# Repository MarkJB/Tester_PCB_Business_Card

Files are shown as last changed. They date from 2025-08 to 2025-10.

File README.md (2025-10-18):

# Tester PCB Business Card

A PCB Business Card designed by a tester, for testers (QA Engineers)

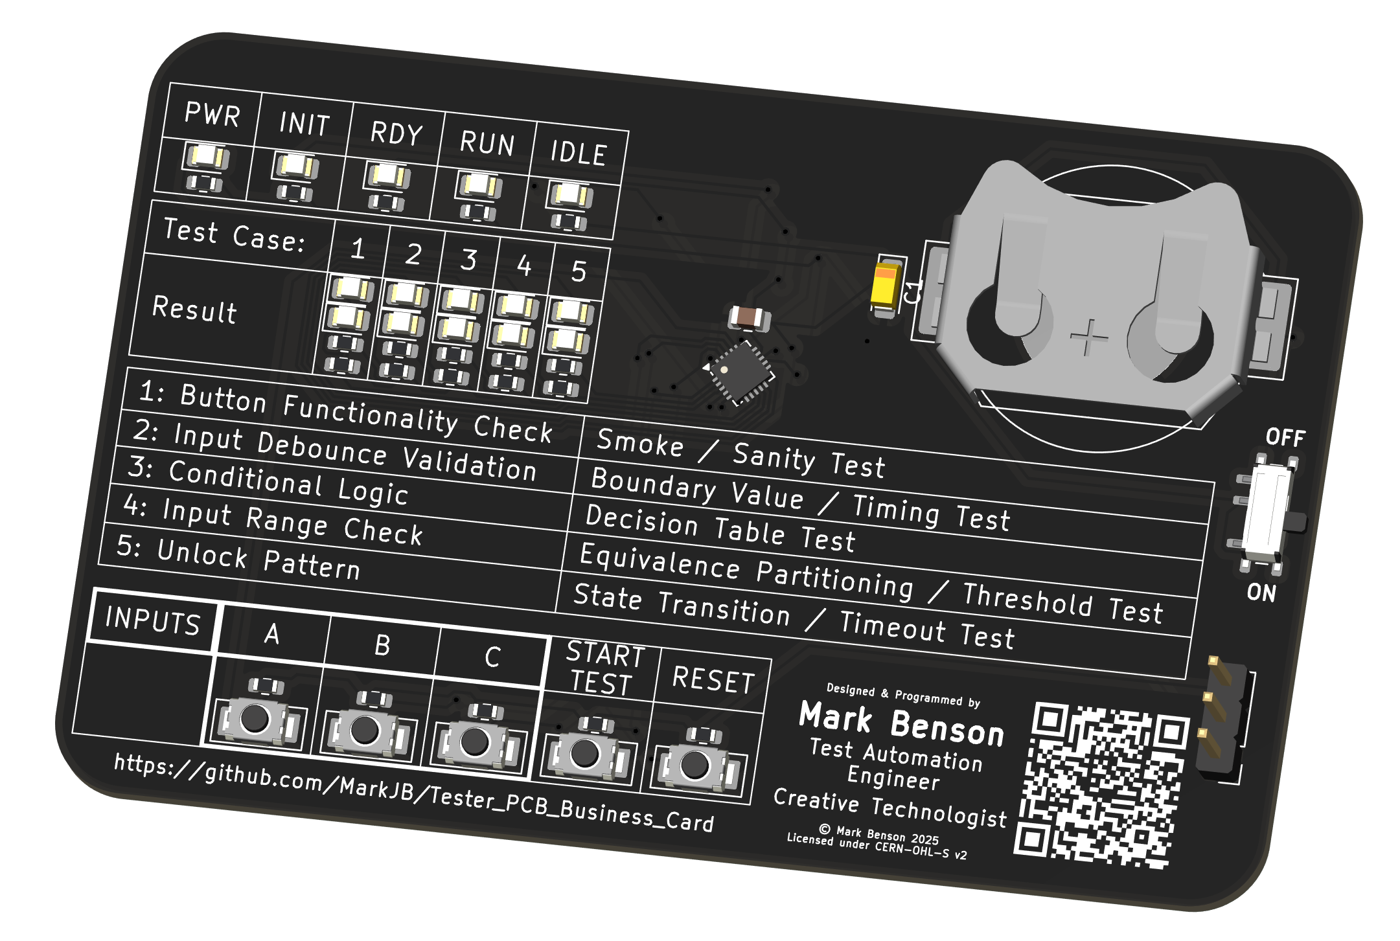
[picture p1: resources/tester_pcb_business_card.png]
Kicad 9 PCB Render


I've always liked the PCB business cards I've seen people design. They often have an interesting story about the why and the how, and sometimes even lead to a job offer as a result!

> Note: For any recruiters or prospective employers who end up here, I'm a software tester specializing in WebUI test automation. Electronics and hardware is a hobby (and occasionally a freelance gig in the Creative Technologist/Arts and Technology space)

I wanted to give it a go but couldn't think of anything compelling that was related to my primary industry (QA, Software Testing & Test Automation). Then I saw a recent [pong example on Hackaday](https://hackaday.com/2025/08/13/pcb-business-card-plays-pong-attracts-employer/) which made me wonder whether the author had done much testing, and that sparked the idea of creating a PCB business card all about testing.

There are 5 'test cases'\*, each one designed to be a little bit harder than the previous one and to focus on a different class of test. The hardware is somewhat limited, so how well each of the tests achieves its intended goal or how true it is to its test type is open for debate and I welcome feedback from actual testers!

The idea is that a tester should be able to look at the test case description, its test type and, given the available inputs and output, figure out how to get the tests to pass, treating it as a sort of black-box exploratory test session. Think of it as a fidget toy for tester.

That all said, I've not yet had any feedback from any testers so I don't know if its too easy or too hard. If you want to cheat, dig into this repo and you'll find the test case BDD scenarios and solutions (which I have deliberately not linked from any of the main READMEs), or as an alternative you can read the code (either the main firmware or the simulator should provide a white-box experience).

\* I use the term "test cases" to refer to the tests that the hardware is presenting to the end user to 'execute', but in some places I have also created actual tests for the code as well (like the Playwright tests for the simulator).

> Note: There may be minor differences between the simulator and the actual hardware due to implementation details or I changed direction while working on the firmware and haven't gotten round to updating the simulator.

So here is Rev A:

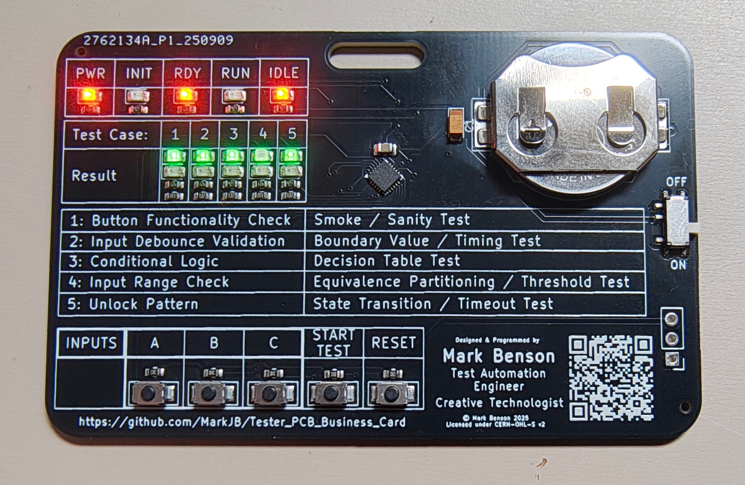
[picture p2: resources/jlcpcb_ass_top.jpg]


This is based on the CH32V003F4U6. A 27¢ micro controller with a one-wire programmer that costs less than $8. I had no experience with this when I started this project, but cost was a big factor with the card. I'm aiming for sub $2 per unit so I can a) afford to get a handful made and b) give them away at conferences and networking events.

> Note: I added a slot for attaching to a lanyard as I intend to give these out at networking and conference events.

This repo includes:

# Hardware

The [schematic](./resources/schematic.pdf), PCB design, BoM and JLCPCB ready production files [Kicad 9 files here](./hardware/)

# Software

## Simulator

Simulator [README](./software/simulator)

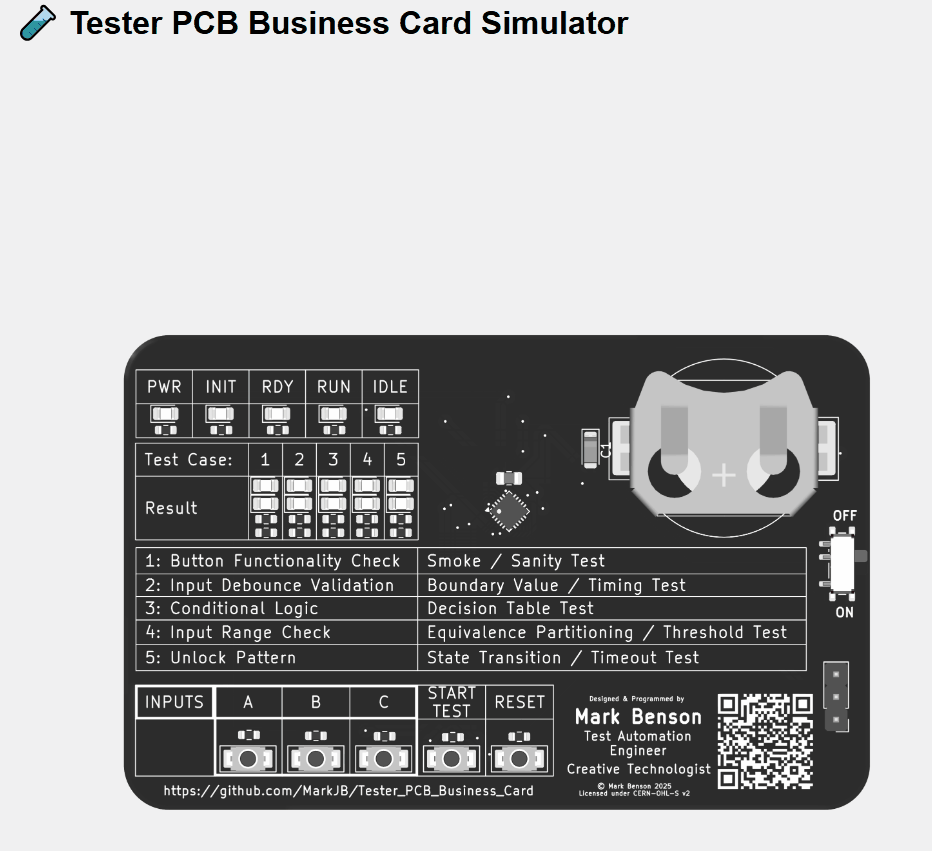
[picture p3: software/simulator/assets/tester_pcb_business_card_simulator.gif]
Tester PCB Preview


The simulator is built, tested and (if successful) deployed to GitHub pages by a [GitHub Actions pipeline](https://github.com/MarkJB/Tester_PCB_Business_Card/actions)

You can play with the deployed simulator here: [Simulator Demo](https://markjb.github.io/Tester_PCB_Business_Card/)

## Firmware

Uses platformio and the ch32fun framework.

[Main firmware](./software/firmware/tester_runtime/): The main firmware containing tests, test case runner, LED control, button functions etc.

[Board check](./software/firmware/board_check/): Simple test firmware to confirm LEDs and buttons are connected and working. Mainly used for testing hand assembled prototype boards.

[LED Tune](./software/firmware/led_tune/): Simple firmware to allow manual tuning of resistor values. shouldn't need this again unless the LEDs are changed for ones that are significantly different.

# Licenses

Copyright Mark Benson 2025

The hardware is licensed under the CERN-OHL-S v2 license.
The software is licensed under the MIT license.

Usual disclaimer - No warranty implied or given for any use or outcome of any of the available materials, etc. 

This isn't a toy, it's not suitable for children. As it's not in a case, there is a risk of short circuiting the components and battery, resulting in damage or overheating, so do not put it in your pocket or bag or anywhere where metal objects could cause short circuit. Note: Battery should be inserted + side up. Incorrectly inserted battery will short out resulting in damage or overheating. Use at your own risk.

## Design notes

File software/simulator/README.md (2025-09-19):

# 🧪 Tester PCB Business Card Simulator

An interactive browser based simulator for the Tester PCB Business Card — designed to evaluate the user experience before the hardware was available. Also to check if the test cases were interesting and engaging and not too obscure for the end user/tester.

Designed in collaboration with Co-pilot - I don't think I'd have been able to spin this up as quickly or get as far as I have in a short space of time without it.

The code went through a number of iterations and ended up informing a lot of decisions that carried over to the real firmware. For instance, I ended up creating a simple test runner with setup and teardown as well as abstracting the hardware. I ended up feeding the test cases along with the BDD scenarios into CoPilot to help generate the test cases for the firmware.

I've also spent some time creating Playwright tests and adding a workflow to build, test and deploy the simulator to github pages. You can test out [the simulator here](https://markjb.github.io/Tester_PCB_Business_Card/)

Simulator Demo  
_Animated preview of the simulator in action - Power on/off, system init, reset, start test, restart test_

---

## 🚀 Getting Started

This simulator runs in the browser using JavaScript and SVG overlays.

### 📦 Prerequisites

- Node

### 🛠 Setup Instructions

1. **Checkout the repo**
   ```bash
   git clone https://github.com/MarkJB/Tester_PCB_Business_Card.git
   ```
2. **Navigate to the simulator folder**
   ```
   cd Tester_PCB_Business_Card/software/simulator
   ```
   3. **Install dependencies**
   ```
   npm ci
   ```
   4. **Start the simulator**
   ```
   npm run dev
   ```
   5. **Open simulator in browser**
   ```
   Go to http://localhost:5173
   ```
   (or whatever port it opens on for you)

### 🛠 Usage Instructions

The power switch toggles the power on/off
The input buttons A, B & C are used in the tests. Pressing one of these will briefly light up the INIT status LED.
The "START TEST" button will start a test run of all tests. Each test runs for 5 seconds. The result will be shown at the end of the test (Green for pass, red for fail, TBD flashing green for warning). Press "START TEST" to advance to the next test or restart the test run when it is finished.
Pressing "RESET" will reset the simulator and test progress.

Its up to you to figure out how to pass all the tests.

Note: There are spoilers/solutions in the repo.

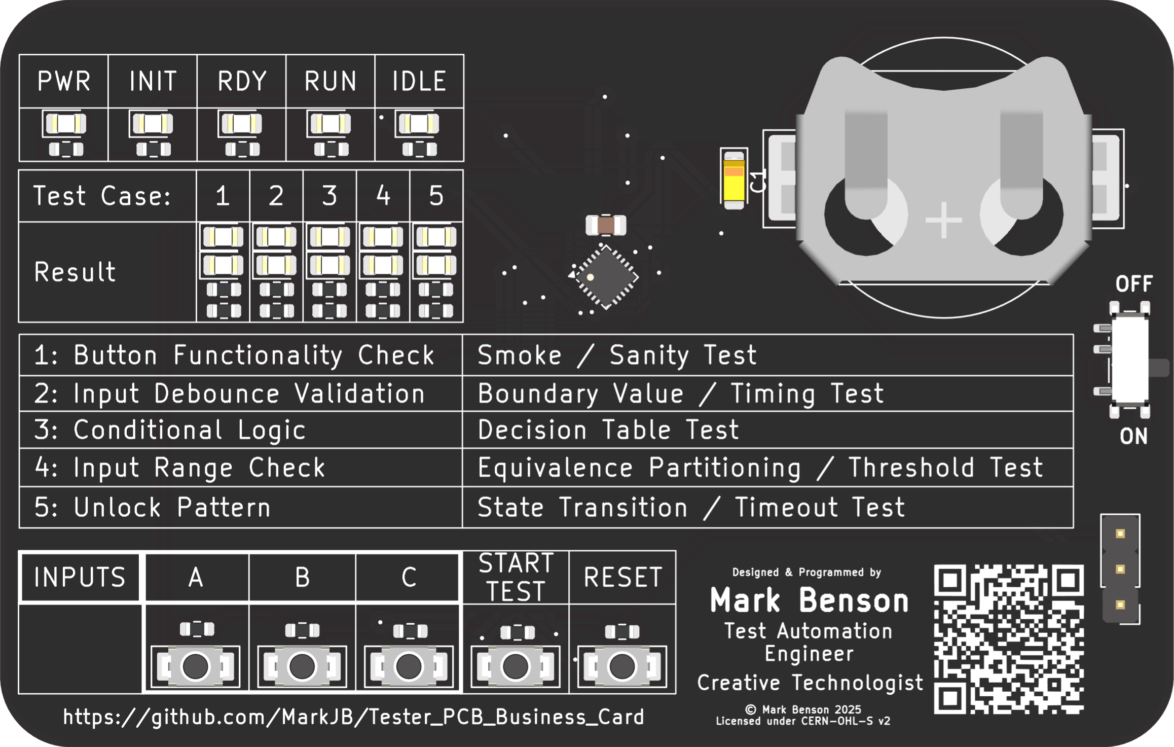
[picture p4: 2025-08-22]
software/simulator/assets/background.png

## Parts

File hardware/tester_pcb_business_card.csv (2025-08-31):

Value | Reference | Footprint | LCSC
CR2032 | BT1 | custom:MY-2032-12 | C964833
10u | C1 | Capacitor_Tantalum_SMD:CP_EIA-3216-18_Kemet-A | C7171
0.1u | C2 | Capacitor_SMD:C_0805_2012Metric | C49678
PWR | D1 | LED_SMD:LED_0805_2012Metric | C84256
INIT | D2 | LED_SMD:LED_0805_2012Metric | C84256
RDY | D3 | LED_SMD:LED_0805_2012Metric | C84256
RUN | D4 | LED_SMD:LED_0805_2012Metric | C84256
RA_R | D6 | LED_SMD:LED_0805_2012Metric | C84256
RB_R | D7 | LED_SMD:LED_0805_2012Metric | C84256
RC_R | D8 | LED_SMD:LED_0805_2012Metric | C84256
RD_R | D9 | LED_SMD:LED_0805_2012Metric | C84256
RE_R | D10 | LED_SMD:LED_0805_2012Metric | C84256
RA_G | D11 | LED_SMD:LED_0805_2012Metric | C2297
RB_G | D12 | LED_SMD:LED_0805_2012Metric | C2297
RD_G | D14 | LED_SMD:LED_0805_2012Metric | C2297
RE_G | D15 | LED_SMD:LED_0805_2012Metric | C2297
IDLE | D5,D13 | LED_SMD:LED_0805_2012Metric | C2297,C84256
SWIO | J1 | Connector_PinHeader_2.54mm:PinHeader_1x03_P2.54mm_Vertical
470 | R1,R2,R3,R4,R5,R11,R13,R15,R17,R19 | Resistor_SMD:R_0603_1608Metric | C23179
3.3k | R12,R14,R16,R18,R20 | Resistor_SMD:R_0603_1608Metric | C22978
10k | R6,R7,R8,R9,R10 | Resistor_SMD:R_0603_1608Metric | C25804
PWR | SW1 | custom:SW_SPDT_Shouhan_MSK12C02 | C431540
A | SW2 | custom:BTN_XUNPU_TS_1088-AR02016 | C720477
B | SW3 | custom:BTN_XUNPU_TS_1088-AR02016 | C720477
C | SW4 | custom:BTN_XUNPU_TS_1088-AR02016 | C720477
D | SW5 | custom:BTN_XUNPU_TS_1088-AR02016 | C720477
RST | SW6 | custom:BTN_XUNPU_TS_1088-AR02016 | C720477
CH32V003FxUx | U1 | Package_DFN_QFN:QFN-20-1EP_3x3mm_P0.4mm_EP1.65x1.65mm | C5299908

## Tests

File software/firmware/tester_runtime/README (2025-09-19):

Compile and upload with PlatformIO (this should automatically fetch the ch32fun framework) using a WCH-LinkE programmer.

Firmware based on design spec, BDD scenarios and simulator (test case) code.

If you have problems uploading via VSCode, try downloading the (openwch/openocd_wch repo)[https://github.com/openwch/openocd_wch]. This repo provides a customized version of the openocd.exe util that works with the WHC-Link-E programmer and running the following command:

openocd_wch\bin\openocd.exe -f openocd_wch\bin\wch-riscv.cfg -c "program path\to\firmware.elf verify reset exit"

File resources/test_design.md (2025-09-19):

# 🧪 Test Suite Overview

| Test Case # | Name | Type |
| --- | --- | --- |
| 1 | Button Functionality Check | Smoke / Sanity Test |
| 2 | Input Debounce Validation  | Boundary Value / Timing Test |
| 3 | Conditional Logic | Decision Table / Branch Test |
| 4 | Input Range Check | Equivalence Partitioning / Threshold Test |
| 5 | Unlock Pattern | State Transition / Timeout Test |

### 💡 Test Result Feedback

| Outcome | LED Behavior |
| --- | --- |
| ✅Pass | 🟢⚫ |
| ⚠️Warning | (🟢/⚫)⚫ (Blinking Green) |
| ❌Fail | ⚫🔴 |

## 🚨⚠️ Warning! Spoilers Ahead!! ⚠️🚨

We should split the test description and the steps/solutions into separate files so this can serve as a test guide without giving away the solution

## 🧪 Test Case 1: Button Functionality Check

**Instruction**: Press each button in turn.  
**Type**: Smoke / Sanity Test

#### Scenario: Validate input button functionality

```gherkin
Given the system state is powered on and in an idle state
When I press each input button in sequence
Then each button press is registered by the system
And the system is ready for further testing
```

---

## 🧪 Test Case 2: Input Debounce Validation – Boundary Value / Timing Test

> ### Note: This needs some clarification of what we are trying to achieve - what are we testing - that it works or rejects?

**Instruction**: Press button B twice with a specific delay between presses.
**Type**: Boundary Value / Timing Test

### Scenario: Validate system debounce threshold using timed input

```gherkin
Given the system is idle and ready to receive input
When I press button B twice with a delay greater than 30ms and less than 200ms
Then the system registers both presses as valid input

Given the system is idle and ready to receive input
When I press button B twice with a delay less than 30ms
Then the system ignores the second press as invalid input (debounce)
```

### 🧠 What’s Being Tested

> “This test models a system that filters out rapid, repeated signals. The tester must press B twice with a precise delay to determine the system’s debounce threshold.”

- **Boundary**: 100ms (tbd)
- **Pass**: Two presses >30ms apart + <200ms apart → both counted
- **Fail**: Two presses <30ms apart → second ignored

### 🔧 Test Logic

| Timing Between Presses | Interpretation | Test Outcome |
| --- | --- | --- |
| >100ms | Treated as valid input | ✅ Pass |
| <100ms | Treated as bounce → ignored | ❌ Fail |

---

## 🧪 Test Case 3: Conditional Logic – Decision Table Test

**Instruction**: Press any combination of A, B, and C within 5 seconds.
**Type**: Decision Table / Branch Test

### Scenario: Evaluate system logic based on input combinations

```gherkin
Given the system is idle and ready to receive input
When the user presses any combination of buttons (individually or combined) A, B, and C within a 5-second window
Then the system stores the input state until the timeout expires
And the system evaluates the final input state against its decision table
```

> Note: Pressing a button will set its state and pressing it again will unset it.

### 🧠 What’s Being Tested

> “This test models decision table logic. The tester must deduce the correct input combination by observing system outcomes and reasoning through partial correctness.”

- **Inputs**: A, B, C
- **Time Limit**: 5 seconds
- **Outcome Types**:
  - ✅ **Pass** → Correct combination
  - ⚠️ **Warning** → Partial match
  - ❌ **Fail** → Incorrect or no input

### 🔧 Test Logic

| A | B | C | Outcome | Reasoning |
| --- | --- | --- | --- | --- |
| 0 | 0 | 0 | Fail | No input → no correct signal |
| 0 | 0 | 1 | Warning | C alone → partial match |
| 0 | 1 | 0 | Warning | B alone → partial match |
| 0 | 1 | 1 | Pass | ✅ B + C → correct combo |
| 1 | 0 | 0 | Fail | A alone → incorrect input |
| 1 | 0 | 1 | Warning | A + C → C is good, A is not |
| 1 | 1 | 0 | Warning | A + B → B is good, A is not |
| 1 | 1 | 1 | Warning | B + C is good, but A degrades combo |

---

## 🧪 Test Case 4: Input Range Check – Equivalence Partitioning / Threshold Test

**Instruction**: Provide values for A, B, and/or C within a 5-second window.
**Type**: Equivalence Partitioning / Threshold Test

### Scenario: System validates input ranges after timeout

```gherkin
Given the system is idle and ready to receive input
When the user provides values for inputs A, B, and/or C within a 5-second window
Then the system stores the final input state at the end of the time window
And the system evaluates each input independently against its valid range
```

### 🧠 What’s Being Tested

> “This test models per-input validation using equivalence partitioning. Each input is evaluated independently against its valid range. It teaches testers to think in terms of input classes and boundary sensitivity.”

### 📊 Example Outcomes

| A | B | C | Outcome Description |
| --- | --- | --- | --- |
| 6 | 8-11 | 3 | ✅ All valid → pass |
| 5 or 7 | 7 or 12 | 2 or 4 | ⚠️ borderline → warning (red flashing - I originally intended to use bicolour LEDs which could produce Green/Red/Orange but they were too expensive) |
| 0 | 2 | 0 | ❌ B invalid → fail |
| 0 | 0 | 0 | ❌ No input → fail |
| 7 | 0 | 0 | ✅ A valid → pass, others ignored |
| 0 | 8 | 0 | ✅ B valid → pass, others ignored |
| 0 | 0 | 3 | ✅ C valid → pass, others ignored |

---

## 🧪 Test Case 5: Unlock Pattern – State Transition / Timeout + Recovery

**Instruction**: Enter the correct unlock code within the time limit.  
**Type**: State Transition, Timeout Handling

---

### 📜 Scenario: System transitions through unlock states based on input sequence

```gherkin
Scenario: Successful unlock
  Given the unlock test is in progress
  When the user enters the sequence A → B → C → B → A
  Then the system transitions through INIT, STEP_1, STEP_2, STEP_3, and STEP_4
  And the system enters the PASS state
  And the system is unlocked

Scenario: Incorrect unlock sequence
  Given the unlock test is in progress
  When the user enters any 5-button sequence that does not match A → B → C → B → A
  Then the system enters the RECOVERY state
  And the test case LEDs stop alternating
  And the FAIL LED blinks rapidly
  And the user has 5 seconds to reset the test by pressing C → C

Scenario: Recovery success
  Given the system is in the RECOVERY state
  When the user presses C → C within 5 seconds
  Then the RECOVERY timeout is cancelled
  And the FAIL LED is cleared
  And the test case LEDs resume alternating
  And the user may retry the unlock sequence

Scenario: Recovery failure
  Given the system is in the RECOVERY state
  When the user does not press C → C within 5 seconds
  Then the system enters the FAIL state
  And the FAIL LED remains solid
```

### 🧭 Objective

Simulate a system requiring a precise unlock pattern:  
`A → B → C → B → A`

- Input must be exactly 5 button presses
- Incorrect sequence triggers recovery opportunity
- Recovery: `C → C` within 5 seconds

---

### 🛠️ Setup

- **Test Duration**: 10 seconds total from first input
- **Input Limit**: Exactly 5 button presses
- **Correct Sequence**:
  1. A → INIT
  2. B → STEP_1
  3. C → STEP_2
  4. B → STEP_3
  5. A → PASS
- **Incorrect Sequence**: Any 5-button input that does not match the above
- **Recovery Trigger**: Only after incorrect 5-button input
- **Recovery Window**: 5 seconds to enter `C → C`
- **Post-Recovery**: Test resets, user may retry

---

### 💡 LED Feedback

| State | LED Behavior |
| --- | --- |
| In Progress | Alternating red/green blink (test case LEDs) |
| PASS | Solid green |
| FAIL | Solid red |
| RECOVERY | Rapid red blink (FAIL LED) |

> Note: Individual button validity is not shown. INIT LED pulses on button press via event handler.

---

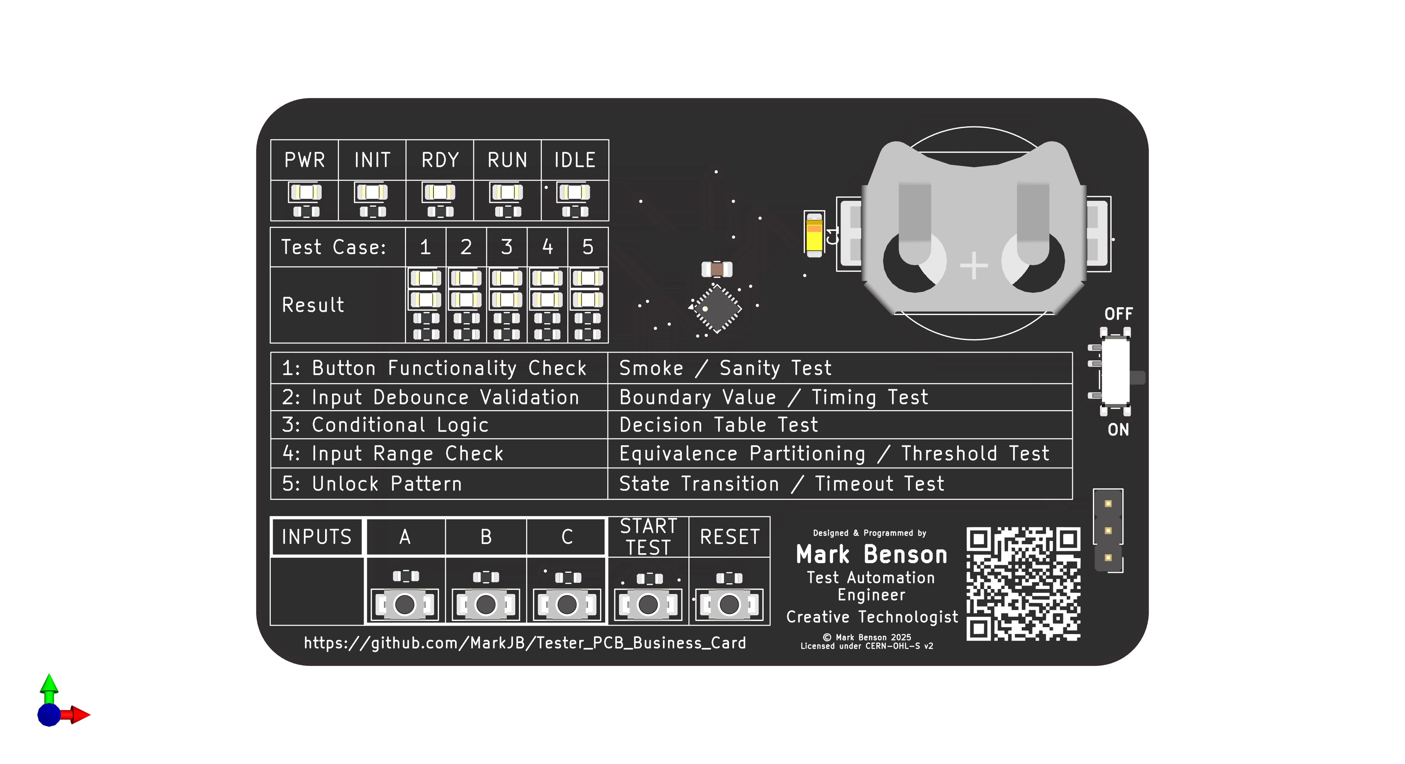
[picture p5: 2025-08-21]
resources/tester_pcb_business_card_top.png

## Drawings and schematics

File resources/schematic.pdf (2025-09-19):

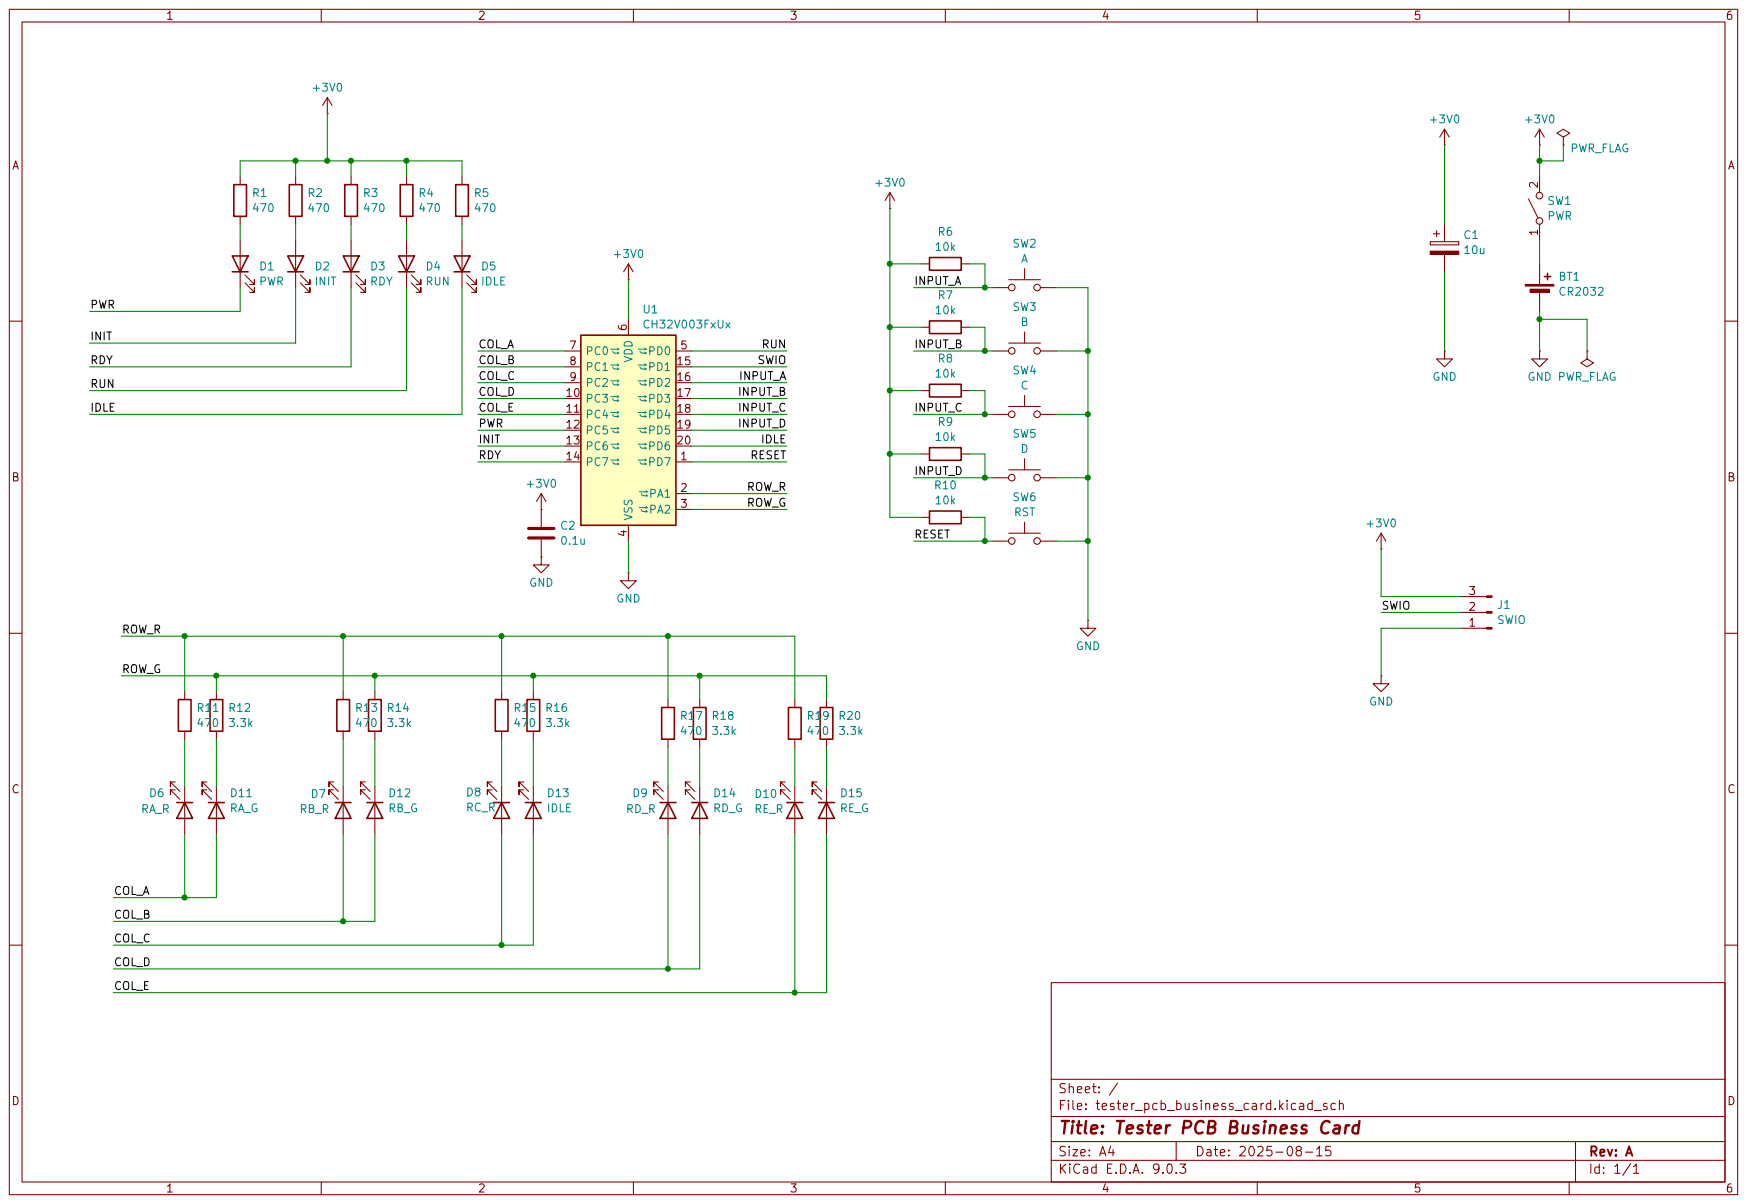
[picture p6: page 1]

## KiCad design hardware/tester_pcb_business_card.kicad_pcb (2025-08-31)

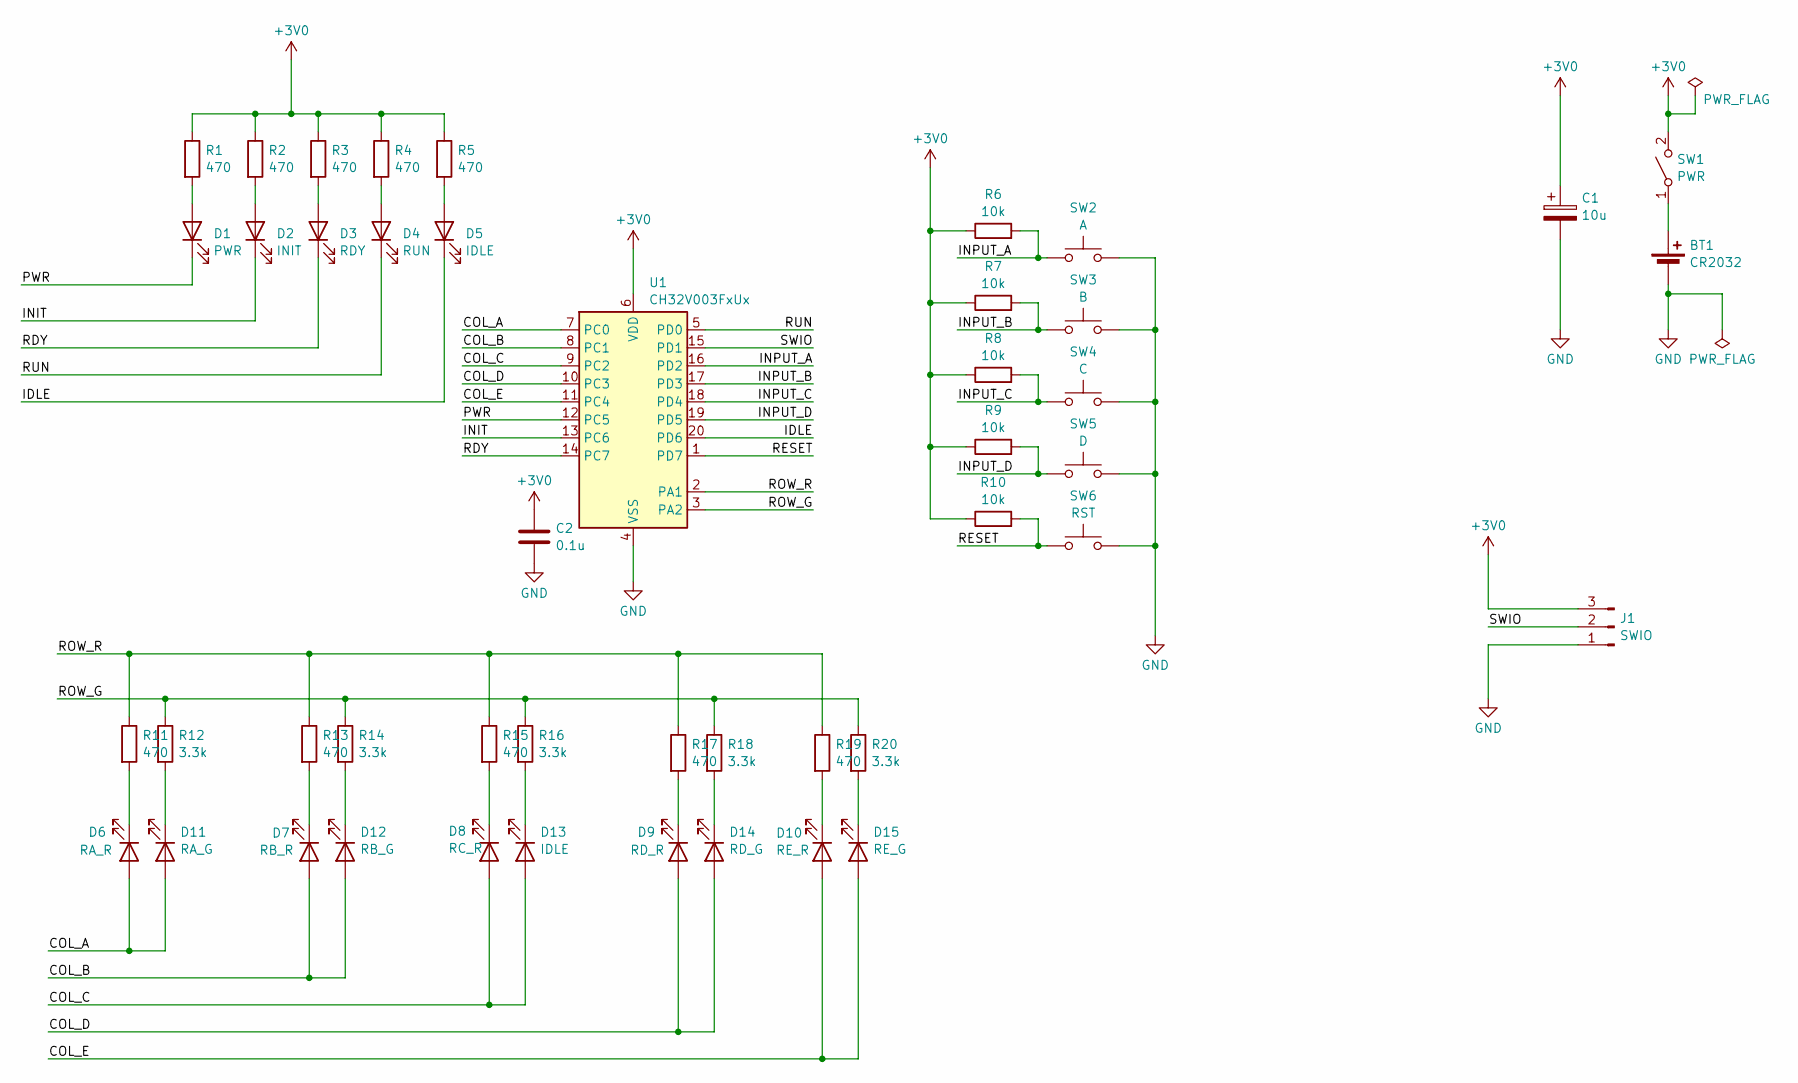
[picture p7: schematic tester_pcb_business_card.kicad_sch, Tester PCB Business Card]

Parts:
BT1: CR2032; MY-2032-12; LCSC C964833
C1: 10u; CP_EIA-3216-18_Kemet-A; LCSC C7171
C2: 0.1u; C_0805_2012Metric; LCSC C49678
D1: PWR; LED_0805_2012Metric; LCSC C84256
D2: INIT; LED_0805_2012Metric; LCSC C84256
D3: RDY; LED_0805_2012Metric; LCSC C84256
D4: RUN; LED_0805_2012Metric; LCSC C84256
D5: IDLE; LED_0805_2012Metric; LCSC C84256
D6: RA_R; LED_0805_2012Metric; LCSC C84256
D7: RB_R; LED_0805_2012Metric; LCSC C84256
D8: RC_R; LED_0805_2012Metric; LCSC C84256
D9: RD_R; LED_0805_2012Metric; LCSC C84256
D10: RE_R; LED_0805_2012Metric; LCSC C84256
D11: RA_G; LED_0805_2012Metric; LCSC C2297
D12: RB_G; LED_0805_2012Metric; LCSC C2297
D13: IDLE; LED_0805_2012Metric; LCSC C2297
D14: RD_G; LED_0805_2012Metric; LCSC C2297
D15: RE_G; LED_0805_2012Metric; LCSC C2297
J1: SWIO; PinHeader_1x03_P2.54mm_Vertical
R1, R2, R3, R4, R5, R11, R13, R15, R17, R19: 470; R_0603_1608Metric; LCSC C23179
R6, R7, R8, R9, R10: 10k; R_0603_1608Metric; LCSC C25804
R12, R14, R16, R18, R20: 3.3k; R_0603_1608Metric; LCSC C22978
SW1: PWR; SW_SPDT_Shouhan_MSK12C02; LCSC C431540
SW2: A; BTN_XUNPU_TS_1088-AR02016; LCSC C720477
SW3: B; BTN_XUNPU_TS_1088-AR02016; LCSC C720477
SW4: C; BTN_XUNPU_TS_1088-AR02016; LCSC C720477
SW5: D; BTN_XUNPU_TS_1088-AR02016; LCSC C720477
SW6: RST; BTN_XUNPU_TS_1088-AR02016; LCSC C720477
U1: CH32V003FxUx; QFN-20-1EP_3x3mm_P0.4mm_EP1.65x1.65mm; LCSC C5299908

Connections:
+3V0: C1.1, C2.1, J1.3, R1.1, R2.1, R3.1, R4.1, R5.1, R6.1, R7.1, R8.1, R9.1, R10.1, SW1.2 (B), U1.6 (VDD)
/COL_A: D6.2 (A), D11.2 (A), U1.7 (PC0)
/COL_B: D7.2 (A), D12.2 (A), U1.8 (PC1)
/COL_C: D8.2 (A), D13.2 (A), U1.9 (PC2)
/COL_D: D9.2 (A), D14.2 (A), U1.10 (PC3)
/COL_E: D10.2 (A), D15.2 (A), U1.11 (PC4)
/IDLE: D5.1 (K), U1.20 (PD6)
/INIT: D2.1 (K), U1.13 (PC6)
/INPUT_A: R6.2, SW2.1, U1.16 (PD2)
/INPUT_B: R7.2, SW3.1, U1.17 (PD3)
/INPUT_C: R8.2, SW4.1, U1.18 (PD4)
/INPUT_D: R9.2, SW5.1, U1.19 (PD5)
/PWR: D1.1 (K), U1.12 (PC5)
/RDY: D3.1 (K), U1.14 (PC7)
/RESET: R10.2, SW6.1, U1.1 (PD7)
/ROW_G: R12.1, R14.1, R16.1, R18.1, R20.1, U1.3 (PA2)
/ROW_R: R11.1, R13.1, R15.1, R17.1, R19.1, U1.2 (PA1)
/RUN: D4.1 (K), U1.5 (PD0)
/SWIO: J1.2, U1.15 (PD1)
GND: BT1.2 (-), C1.2, C2.2, J1.1, SW2.2, SW3.2, SW4.2, SW5.2, SW6.2, U1.4 (VSS), U1.21 (VSS)
unnamed: BT1.1 (+), SW1.1 (A)
unnamed: D1.2 (A), R1.2
unnamed: D2.2 (A), R2.2
unnamed: D3.2 (A), R3.2
unnamed: D4.2 (A), R4.2
unnamed: D5.2 (A), R5.2
unnamed: D6.1 (K), R11.2
unnamed: D7.1 (K), R13.2
unnamed: D8.1 (K), R15.2
unnamed: D9.1 (K), R17.2
unnamed: D10.1 (K), R19.2
unnamed: D11.1 (K), R12.2
unnamed: D12.1 (K), R14.2
unnamed: D13.1 (K), R16.2
unnamed: D14.1 (K), R18.2
unnamed: D15.1 (K), R20.2

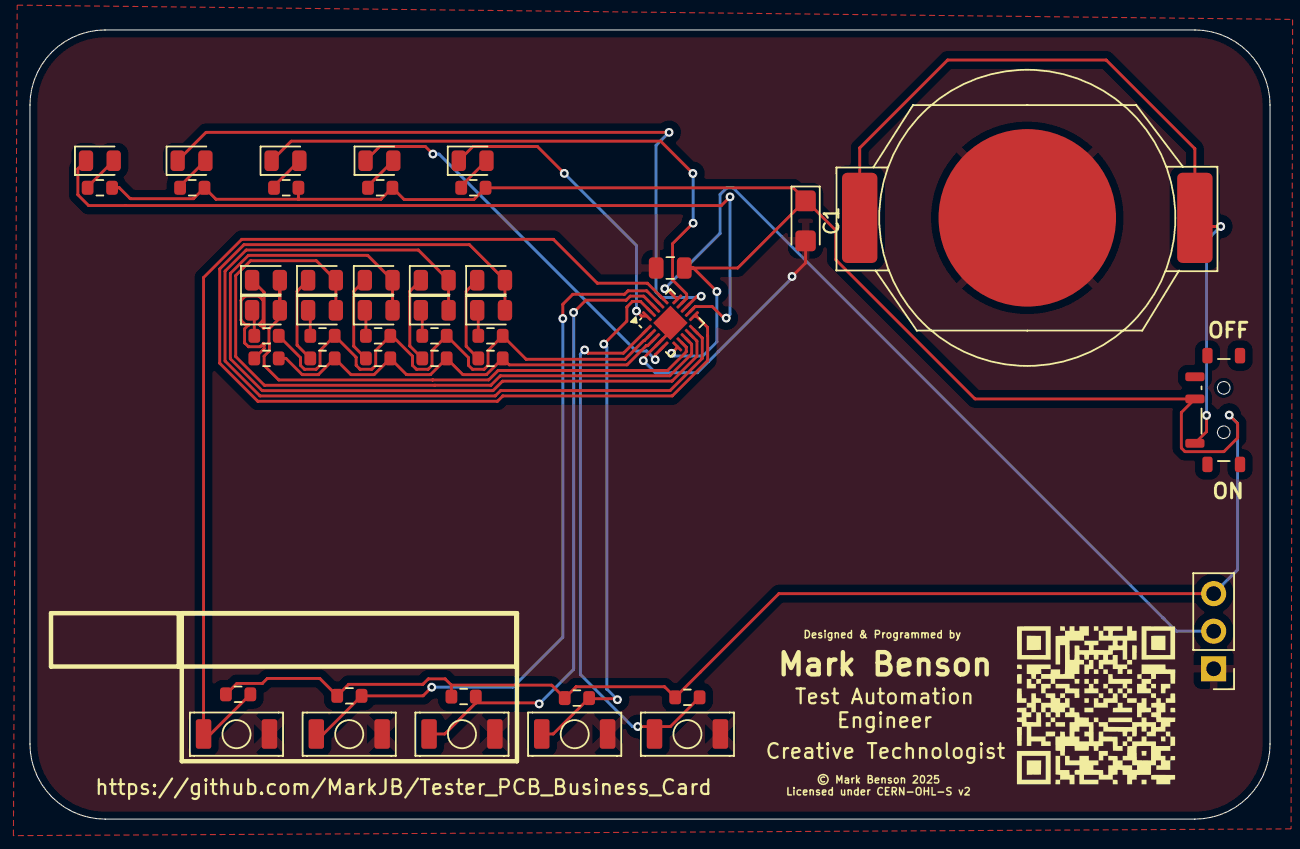
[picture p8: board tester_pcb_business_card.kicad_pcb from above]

Board: 2 copper layers, 83.8 x 53.3 mm, 46 parts (0 on the bottom side), 36 nets.

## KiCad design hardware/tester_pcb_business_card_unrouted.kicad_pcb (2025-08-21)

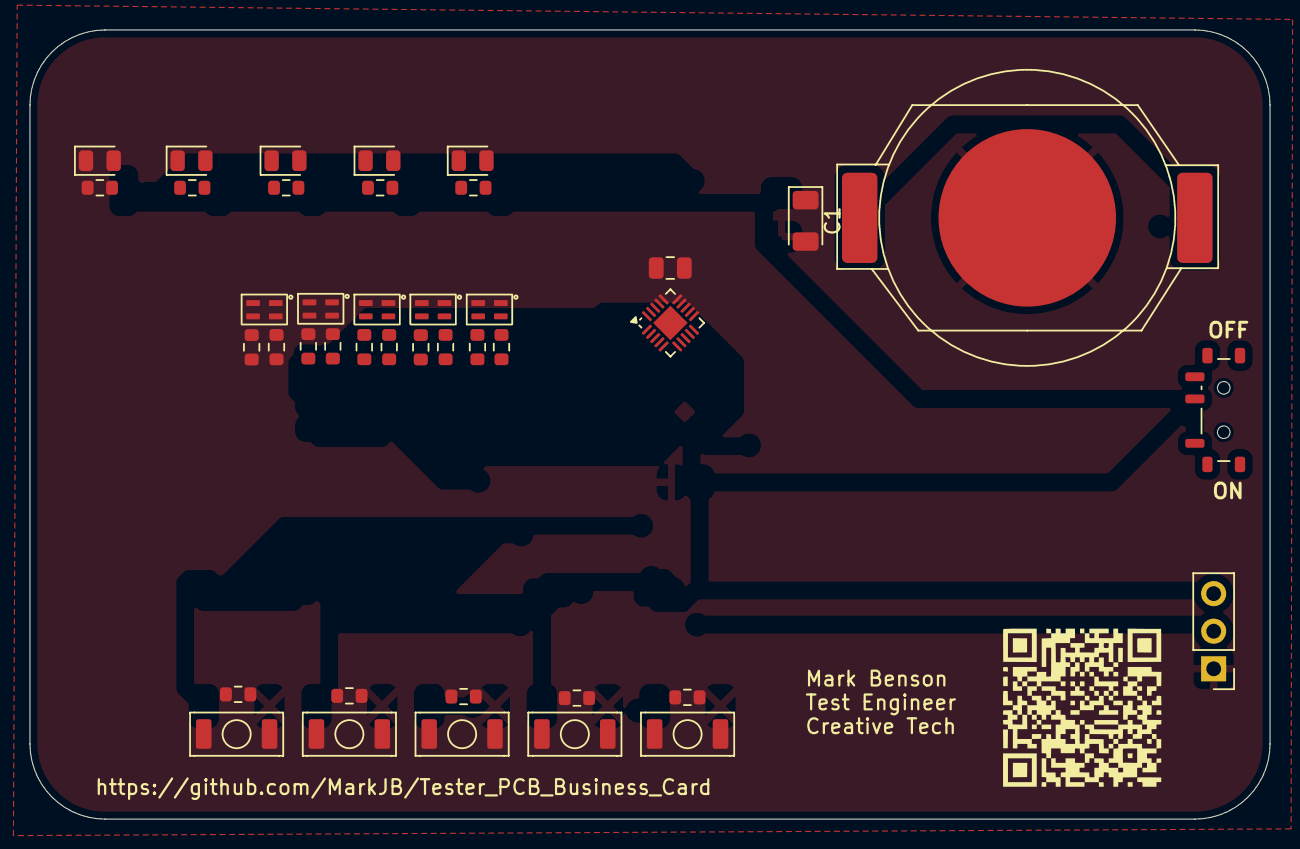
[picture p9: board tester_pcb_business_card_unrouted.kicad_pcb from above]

Board: 2 copper layers, 83.8 x 53.3 mm, 41 parts (0 on the bottom side), 36 nets, no tracks yet.

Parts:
BT1: CR2032; MY-2032-12
C1: 10u; D_1206_3216Metric
C2: 0.1u; C_0805_2012Metric
D1: PWR; LED_0805_2012Metric
D2: INIT; LED_0805_2012Metric
D3: RDY; LED_0805_2012Metric
D4: RUN; LED_0805_2012Metric
D5: IDLE; LED_0805_2012Metric
D6: C; SML-522
D7: A; SML-522
D8: B; SML-522
D9: E; SML-522
D10: D; SML-522
J1: SWIO; PinHeader_1x03_P2.54mm_Vertical
R1, R2, R3, R4, R5, R11, R13, R15, R17, R19: 220; R_0603_1608Metric
R6, R7, R8, R9, R10: 10k; R_0603_1608Metric
R12, R14, R16, R18, R20: 100; R_0603_1608Metric
SW1: PWR; SW_SPDT_Shouhan_MSK12C02
SW2: A; BTN_XUNPU_TS_1088-AR02016
SW3: B; BTN_XUNPU_TS_1088-AR02016
SW4: C; BTN_XUNPU_TS_1088-AR02016
SW5: D; BTN_XUNPU_TS_1088-AR02016
SW6: RST; BTN_XUNPU_TS_1088-AR02016
U1: CH32V003FxUx; QFN-20-1EP_3x3mm_P0.4mm_EP1.65x1.65mm

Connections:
+3V0: C1.1, C2.1, J1.3, R1.1, R2.1, R3.1, R4.1, R5.1, R6.1, R7.1, R8.1, R9.1, R10.1, SW1.2 (B), U1.6 (VDD)
/COL_G: R12.1, R13.1, R15.1, R17.1, R19.1, U1.3 (PA2)
/COL_R: R11.1, R14.1, R16.1, R18.1, R20.1, U1.2 (PA1)
/IDLE: D5.2 (A), U1.20 (PD6)
/INIT: D2.2 (A), U1.13 (PC6)
/INPUT_A: R6.2, SW2.1, U1.16 (PD2)
/INPUT_B: R7.2, SW3.1, U1.17 (PD3)
/INPUT_C: R8.2, SW4.1, U1.18 (PD4)
/INPUT_D: R9.2, SW5.1, U1.19 (PD5)
/PWR: D1.2 (A), U1.12 (PC5)
/RDY: D3.2 (A), U1.14 (PC7)
/RESET: R10.2, SW6.1, U1.1 (PD7)
/ROW_A: D7.1 (A1), D7.3 (A2), U1.7 (PC0)
/ROW_B: D8.1 (A1), D8.3 (A2), U1.8 (PC1)
/ROW_C: D6.1 (A1), D6.3 (A2), U1.9 (PC2)
/ROW_D: D10.1 (A1), D10.3 (A2), U1.10 (PC3)
/ROW_E: D9.1 (A1), D9.3 (A2), U1.11 (PC4)
/RUN: D4.2 (A), U1.5 (PD0)
/SWIO: J1.2, U1.15 (PD1)
GND: BT1.2 (-), C1.2, C2.2, J1.1, SW2.2, SW3.2, SW4.2, SW5.2, SW6.2, U1.4 (VSS), U1.21 (VSS)
unnamed: BT1.1 (+), SW1.1 (A)
unnamed: D1.1 (K), R1.2
unnamed: D2.1 (K), R2.2
unnamed: D3.1 (K), R3.2
unnamed: D4.1 (K), R4.2
unnamed: D5.1 (K), R5.2
unnamed: D6.2 (K1), R15.2
unnamed: D6.4 (K2), R16.2
unnamed: D7.2 (K1), R11.2
unnamed: D7.4 (K2), R12.2
unnamed: D8.2 (K1), R13.2
unnamed: D8.4 (K2), R14.2
unnamed: D9.2 (K1), R19.2
unnamed: D9.4 (K2), R20.2
unnamed: D10.2 (K1), R17.2
unnamed: D10.4 (K2), R18.2

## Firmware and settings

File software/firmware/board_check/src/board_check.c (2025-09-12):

#include "ch32fun.h"
#include <stdio.h>
#include <stdbool.h>

// Status Pins
#define PIN_PWR   PC5
#define PIN_INIT  PC6
#define PIN_RDY   PC7
#define PIN_RUN   PD0
#define PIN_IDLE  PD6

// Test Case Columns (TC1–TC5)
#define PIN_COL_A PC0
#define PIN_COL_B PC1
#define PIN_COL_C PC2
#define PIN_COL_D PC3
#define PIN_COL_E PC4

// Test Case Rows
#define PIN_ROW_R PA1  // Red (fail)
#define PIN_ROW_G PA2  // Green (pass)

// Input buttons
#define PIN_INPUT_A  PD2
#define PIN_INPUT_B  PD3
#define PIN_INPUT_C  PD4
#define PIN_INPUT_D  PD5

// Reset button is connected to NRST pin PD7 which should reset the MCU when pressed.
// This is a a hardware feature and does not require configuration.

const uint8_t statusLEDs[] = { PIN_INIT, PIN_RDY, PIN_RUN, PIN_IDLE };
const uint8_t cols[] = { PIN_COL_A, PIN_COL_B, PIN_COL_C, PIN_COL_D, PIN_COL_E };
const uint8_t inputPins[] = { PIN_INPUT_A, PIN_INPUT_B, PIN_INPUT_C, PIN_INPUT_D };
const uint8_t inputCols[] = { PIN_COL_A, PIN_COL_B, PIN_COL_C, PIN_COL_D }; // TC1–TC4
typedef enum {
    MODE_DEMO,
    MODE_INPUT
} BoardMode;

BoardMode currentMode = MODE_DEMO;
void runInputMode(void);

void setupPins() {
    funGpioInitAll();

    // Status LEDs
    funPinMode(PIN_PWR, GPIO_Speed_10MHz | GPIO_CNF_OUT_PP);
    funDigitalWrite(PIN_PWR, FUN_LOW); // Turn PWR ON immediately

    for (int i = 0; i < 4; i++) {
        funPinMode(statusLEDs[i], GPIO_Speed_10MHz | GPIO_CNF_OUT_PP);
        funDigitalWrite(statusLEDs[i], FUN_HIGH); // Ensure all status LEDs start OFF
    }

    // Test Case LEDs
    for (int i = 0; i < 5; i++) {
        funPinMode(cols[i], GPIO_Speed_10MHz | GPIO_CNF_OUT_PP);
        funDigitalWrite(cols[i], FUN_LOW); // Start all columns LOW
    }

    funPinMode(PIN_ROW_R, GPIO_Speed_10MHz | GPIO_CNF_OUT_PP);
    funPinMode(PIN_ROW_G, GPIO_Speed_10MHz | GPIO_CNF_OUT_PP);
    funDigitalWrite(PIN_ROW_R, FUN_HIGH); // Start rows OFF
    funDigitalWrite(PIN_ROW_G, FUN_HIGH);

    for (int i = 0; i < 4; i++) {
    funPinMode(inputPins[i], GPIO_CNF_IN_PUPD);
    funDigitalWrite(inputPins[i], FUN_HIGH); // enable pull‑up
}

}

bool isAnyButtonPressed() {
    for (int i = 0; i < 4; i++) {
        if (funDigitalRead(inputPins[i]) == FUN_LOW) {
            return true;
        }
    }
    return false;
}

void delayWithInputCheck(uint16_t ms) {
    uint16_t step = 5;
    for (uint16_t i = 0; i < ms; i += step) {
        if (isAnyButtonPressed()) {
            currentMode = MODE_INPUT;
            runInputMode(); // never returns
        }
        Delay_Ms(step);
    }
}

void blinkStatusSequence() {
    funDigitalWrite(PIN_PWR, FUN_LOW); // PWR stays on

    for (int i = 0; i < 4; i++) {
        funDigitalWrite(statusLEDs[i], FUN_LOW);
        delayWithInputCheck(200); // or delayWithInputCheck(100)
        funDigitalWrite(statusLEDs[i], FUN_HIGH);
        delayWithInputCheck(200); // or delayWithInputCheck(100)
    }
}

void scanTestCases() {
    for (int i = 0; i < 5; i++) {
        for (int j = 0; j < 5; j++) funDigitalWrite(cols[j], FUN_LOW);
        funDigitalWrite(PIN_ROW_G, FUN_HIGH);
        funDigitalWrite(PIN_ROW_R, FUN_HIGH);

        funDigitalWrite(cols[i], FUN_HIGH);
        funDigitalWrite(PIN_ROW_G, FUN_LOW);
        delayWithInputCheck(200); // or delayWithInputCheck(100)

        funDigitalWrite(PIN_ROW_G, FUN_HIGH);
        funDigitalWrite(PIN_ROW_R, FUN_LOW);
        delayWithInputCheck(200); // or delayWithInputCheck(100)

        funDigitalWrite(cols[i], FUN_LOW);
        funDigitalWrite(PIN_ROW_R, FUN_HIGH);
    }
}

void runInputMode() {
    // Turn off all LEDs except PWR
    for (int i = 0; i < 4; i++) funDigitalWrite(statusLEDs[i], FUN_HIGH);
    for (int i = 0; i < 5; i++) funDigitalWrite(cols[i], FUN_LOW);
    funDigitalWrite(PIN_ROW_R, FUN_HIGH);
    funDigitalWrite(PIN_ROW_G, FUN_HIGH);

    while (1) {
        bool anyPressed = false;

        for (int i = 0; i < 4; i++) {
            if (funDigitalRead(inputPins[i]) == FUN_LOW) {
                funDigitalWrite(inputCols[i], FUN_HIGH);
                anyPressed = true;
            } else {
                funDigitalWrite(inputCols[i], FUN_LOW);
            }
        }

        funDigitalWrite(PIN_ROW_G, anyPressed ? FUN_LOW : FUN_HIGH);
        Delay_Ms(50); // Responsive polling
    }
}

int main() {
    SystemInit();
    setupPins();

    while (1) {
        if (currentMode == MODE_DEMO) {
            if (isAnyButtonPressed()) {
                currentMode = MODE_INPUT;
                runInputMode(); // never returns
            }

            blinkStatusSequence();
            scanTestCases();
            Delay_Ms(500);
        }
    }
}

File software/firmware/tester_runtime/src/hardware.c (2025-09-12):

#include <stdint.h>
#include <stdbool.h>
#include "ch32fun.h"
#include "pins.h"
#include "hardware.h"
#include "buttons.h"
#include "leds.h"
#include "globals.h"
#include "pins.h"

// Pin port/mask arrays/structs (define here)
const PinDef COL[5] = {
    {GPIOC, 0x01}, {GPIOC, 0x02}, {GPIOC, 0x04}, {GPIOC, 0x08}, {GPIOC, 0x10}
};
const PinDef ROW_RED   = { GPIOA, 0x02 };
const PinDef ROW_GREEN = { GPIOA, 0x04 };
const PinDef BTN[4] = {
    {GPIOD, 0x04}, {GPIOD, 0x08}, {GPIOD, 0x10}, {GPIOD, 0x20}
};

// Global variables (define here)
volatile uint32_t msTicks = 0;
volatile bool flashState = false;
volatile bool rapidFlashState = false;
volatile bool runMode = false;
volatile uint8_t currentCol = 0;

static const int statusLEDs[] = { PIN_PWR, PIN_INIT, PIN_RDY, PIN_RUN, PIN_IDLE };
static const int testCols[]   = { PIN_COL_A, PIN_COL_B, PIN_COL_C, PIN_COL_D, PIN_COL_E };
static const int inputPins[]  = { PIN_INPUT_A, PIN_INPUT_B, PIN_INPUT_C, PIN_INPUT_D };

// Timer ISR for 1ms tick, button polling, and LED scan
void TIM1_UP_IRQHandler(void) INTERRUPT_DECORATOR;
void TIM1_UP_IRQHandler(void)
{
    if (TIM1->INTFR & TIM_UIF) {
        TIM1->INTFR &= ~TIM_UIF;
        msTicks++;
        pollButtons();
        static uint32_t nextFlashAt = 250;
        if (msTicks >= nextFlashAt) {
            nextFlashAt += 250;
            flashState = !flashState;
        }
        static uint32_t nextRapidFlashAt = 125;
        if (msTicks >= nextRapidFlashAt) {
            nextRapidFlashAt += 125;
            rapidFlashState = !rapidFlashState;
        }
        scanStep();
    }
}

void setupPins(void) {
    funGpioInitAll();
    RCC->APB2PCENR |= RCC_APB2Periph_GPIOA | RCC_APB2Periph_GPIOC | RCC_APB2Periph_GPIOD;
    for (int i = 0; i < 5; i++) {
        funPinMode(statusLEDs[i], GPIO_Speed_10MHz | GPIO_CNF_OUT_PP);
        funDigitalWrite(statusLEDs[i], FUN_HIGH);
    }
    for (int i = 0; i < 5; i++) {
        funPinMode(testCols[i], GPIO_Speed_10MHz | GPIO_CNF_OUT_PP);
        funDigitalWrite(testCols[i], FUN_LOW);
    }
    funPinMode(PIN_ROW_R, GPIO_Speed_10MHz | GPIO_CNF_OUT_PP);
    funPinMode(PIN_ROW_G, GPIO_Speed_10MHz | GPIO_CNF_OUT_PP);
    funDigitalWrite(PIN_ROW_R, FUN_HIGH);
    funDigitalWrite(PIN_ROW_G, FUN_HIGH);
    for (int i = 0; i < 4; i++) {
        funPinMode(inputPins[i], GPIO_CNF_IN_PUPD);
        funDigitalWrite(inputPins[i], FUN_HIGH);
    }
}

void setupStatusFlasher(void) {
    RCC->APB2PCENR |= RCC_APB2Periph_TIM1;
    RCC->APB2PRSTR |= RCC_APB2Periph_TIM1;
    RCC->APB2PRSTR &= ~RCC_APB2Periph_TIM1;
    TIM1->PSC    = 48 - 1;
    TIM1->ATRLR  = 1000 - 1;
    TIM1->SWEVGR |= TIM_UG;
    TIM1->INTFR  &= ~TIM_UIF;
    TIM1->DMAINTENR |= TIM_UIE;
    NVIC_EnableIRQ(TIM1_UP_IRQn);
    TIM1->CTLR1 |= TIM_CEN;
}

void runStatus(bool isRun) {
    runMode = isRun;
    funDigitalWrite(PIN_RUN,  FUN_HIGH);
    funDigitalWrite(PIN_IDLE, FUN_HIGH);
}

void waitTicks(uint32_t ticks) {
    uint32_t start = msTicks;
    while ((uint32_t)(msTicks - start) < ticks) {
        __WFI();
    }
}

void scanStep(void) {
    static int8_t prev = -1;
    if (activeStates == NULL) {
        gpio_set(ROW_RED.port,   ROW_RED.mask);
        gpio_set(ROW_GREEN.port, ROW_GREEN.mask);
        return;
    }
    gpio_set(ROW_RED.port,   ROW_RED.mask);
    gpio_set(ROW_GREEN.port, ROW_GREEN.mask);
    if (prev >= 0 && prev < 5) {
        if (COL[prev].port != NULL) {
            gpio_clear(COL[prev].port, COL[prev].mask);
        }
    }
    if (currentCol >= 0 && currentCol < 5) {
        TestCaseState state = activeStates[currentCol];
        switch (state) {
            case TC_PASS:
                gpio_clear(ROW_GREEN.port, ROW_GREEN.mask);
                break;
            case TC_FAIL:
                gpio_clear(ROW_RED.port, ROW_RED.mask);
                break;
            case TC_IN_PROGRESS:
                if (flashState)
                    gpio_clear(ROW_RED.port, ROW_RED.mask);
                else
                    gpio_clear(ROW_GREEN.port, ROW_GREEN.mask);
                break;
            case TC_WARNING:
                if (flashState)
                    gpio_clear(ROW_RED.port, ROW_RED.mask);
                break;
            case TC_RETRY:
                if (rapidFlashState)
                    gpio_clear(ROW_RED.port, ROW_RED.mask);
                break;
            case TC_NO_RESULT:
            default:
                break;
        }
        if (COL[currentCol].port != NULL) {
            gpio_set(COL[currentCol].port, COL[currentCol].mask);
        }
    }
    prev = currentCol;
    currentCol = (currentCol + 1) % 5;
}

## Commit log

2025-08-21 Create .gitignore
    Excludes for kicad
2025-08-21 PCB initial commit
    [tester_pcb_business_card-B_Cu.gbl, tester_pcb_business_card-B_Mask.gbs, tester_pcb_business_card-B_Paste.gbp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]
2025-08-21 Renders of PCB
2025-08-23 Add 'glow' effect to LEDs
2025-08-23 Add test case 2, test case 'runner' and a bit of clean up of LED helper functions and comments
2025-08-23 Add test case 3 and fix system state on boot
2025-08-23 Add visual indication to show which test is in progress
    Code needs cleaning up as we now have to clear the state of the test case LEDs before showing the final result - this could be done in a helper function.
2025-08-24 Add test case 4 and improve LED handling
2025-08-24 Add setup and teardown to test runner and make use of that in tests
    Hopefully this will make creating test case 5 a bit easier.
    It should also help to extract the system logic from the test cases. As this is a simulator built to test how the card will behave when running these tests, the boundary between system behaviour and 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
2025-08-24 Update the Gherkin for test case 5 based on some early play testing
2025-08-25 Convert playwright tests to page/flow object model pattern
2025-08-25 3rd pass at modularization - fix introduced issues
    The copilot led refactor was interesting - it lost or threw away a bunch of code and either the separation showed up or introduced some issues around timeouts not being cleared.
2025-08-26 Add status LED tests and improve other tests
2025-08-29 Update test case 5 again
2025-08-29 Clean up test case 5
2025-08-29 Add test case 5
2025-08-29 Refactor code to support test case 5
    Clean up timeout handling code and visual cue control
2025-08-31 Update LED resistor values after tuning
    LEDs were way too bright with chosen resistor values. Tuned so all LEDs are of a similar brightness and to reduce current draw.
    [tester_pcb_business_card.csv, tester_pcb_business_card.kicad_pcb, tester_pcb_business_card.kicad_sch]
2025-08-31 Fix test case LEDs rows and cols
    I had them labelled the wrong way round. Didn't affect anything but it was confusing when referring to schematic when writing code for the test case LEDs.
    [tester_pcb_business_card.kicad_pcb, tester_pcb_business_card.kicad_sch]
2025-08-31 Add firmware/utility for manually tuning LED resistors
    This powers on the power status LED, the TC1 pass and fail LEDs to allow manual tuning of resistor values
    [tune_led_reistors.c]
2025-08-31 Board check firmware
    Initial test firmware that powers on the PWR LED, then briefly turns on each status LED in turn, followed by the test case LEDs.
    This is intended to test that the board functions are working correctly.
    Currently only checks the LEDs. Button check still to be added.
2025-09-01 Add button checks
    System starts up. PWR LED turns on. Other status LEDs light one after the other, followed by test case LEDs. Pattern repeats until an input button is pressed. Then the system switches into button tes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
2025-09-02 Main firmware initial commit
    So far all this does is display a startup sequence. The RUN/IDLE LED flashing is handled by a timer and ISR.
2025-09-02 Scan test case LEDs
    Partially working - does not update when using Delay or waitTicks
    Added config for hardware debugging in platformio/vscode
2025-09-05 commit just to save the code at this stage
2025-09-05 Working ISR
    Note: After a couple of days trying to track down hard faults, turns out it was down to the type of interrupt used.
    From what I understand "WCH-Interrupt-fast" is expecting the ISR to be stack safe - that is to say, don't call anything that touches the stack (library calls, functions, variables etc). Added the con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
2025-09-07 Fix button input state config
    [main.c]
2025-09-07 Fix input button config
    [board_check.c]
2025-09-07 Basic test case runner
2025-09-16 Make button press states easier to debug and tests less flaky
2025-09-16 Use Status LEDs to avoid test case LED matrix timing issues
    [utils.c]
2025-09-19 Add 'MoT 2025' PoV message
    Eye catching led flashing mode
2025-09-19 Update readme adding a photo of the actual production board
2025-10-16 firmware: only allow demo mode when no tests are selected (currentTest == 0)

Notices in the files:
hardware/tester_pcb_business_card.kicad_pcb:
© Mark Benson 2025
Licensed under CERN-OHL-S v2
